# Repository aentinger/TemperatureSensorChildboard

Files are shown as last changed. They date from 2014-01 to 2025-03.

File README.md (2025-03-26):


💾 Temperatursensor Childboard
==============================



# 📸 Image

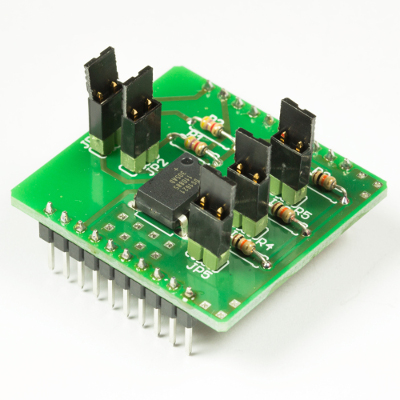
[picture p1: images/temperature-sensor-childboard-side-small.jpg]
LXRobotics P6_2 Temperatursensor Childboard


# 📂 Description

The LXRobotics Temperature Sensor Childboard offers the possiblity to measure the current temperature with high accuracy. In combination with a Radio Shield a wireless sensor network could be formed for monitoring the temperature in each room of an apartment/house. The thermostat function allows the execution of any action when a preset temperature thresholds is exceeded. For a quick and easy start, an open source Arduino library with sample programs is available.

**Features**

* Temperature range -55 °C to +125 °C
* Thermostat function
* Usage of I2C - only 2 Arduino pins required
* 8 possible I2C addresses configurable via jumpers
* Can be used with the Radioshield the Childboard Adaptershield
* Arduino Library with example programs is available on GitHub

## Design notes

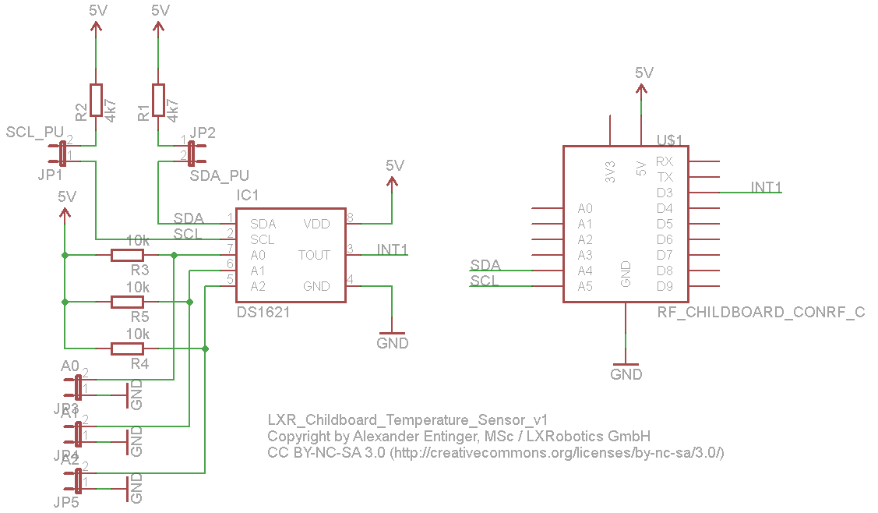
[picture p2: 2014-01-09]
hardware/lxr_childboard_temperature_sensor_v1.png

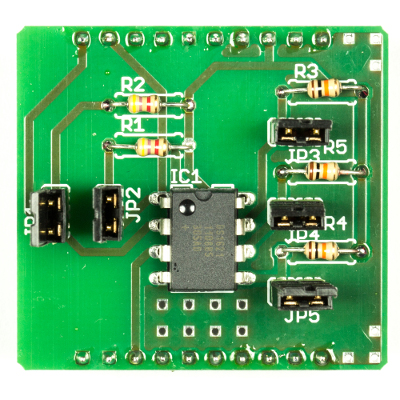
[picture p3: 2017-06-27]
images/temperature-sensor-childboard-top-small.jpg

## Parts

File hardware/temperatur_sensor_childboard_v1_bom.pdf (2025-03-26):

Menge | Schaltplan | Bezeichnung | Farnell/Conrad Bestell Nummer | Preis (1 Stück) | Gesamtpreis | Wird bestückt | Footprint | Säckchen | ESD
2 | U1 | RF Childboard Connector | 1022261 | € 0,36 | € 0,72 | | | S1
1 | IC1 | DS1621, I2C Temperatursensor | 1188024 | € 5,45 | € 5,45 | | | S2 | x
2 | R1, R2 | Widerstand, bedrahtet, 4k7, 1/8 W | 1700245 | € 0,01 | € 0,03 | | | S1
5 | JP1, JP2, JP3, JP4, JP5 | Stiftleiste, 1 x 2, 2.54 mm, Vertikal, Durchsteck | 3418285 | € 0,24 | € 1,20
5 | | Jumper, 2.54 mm, 2 Polig | 4218176 | € 0,14 | € 0,68 | | | S2 | x
3 | R3, R4, R5 | Widerstand, bedrahtet, 10 k, 1/4 W | 2329474 | € 0,03 | € 0,09
1 | Leitfähiger Schaumstoff | 1687855 | € | 2,40 | € | 2,40 | - | Bestellung von 1 Stück reicht für 50 Temperatursensor Childboards aus
| | | Summe | | € | 8,17

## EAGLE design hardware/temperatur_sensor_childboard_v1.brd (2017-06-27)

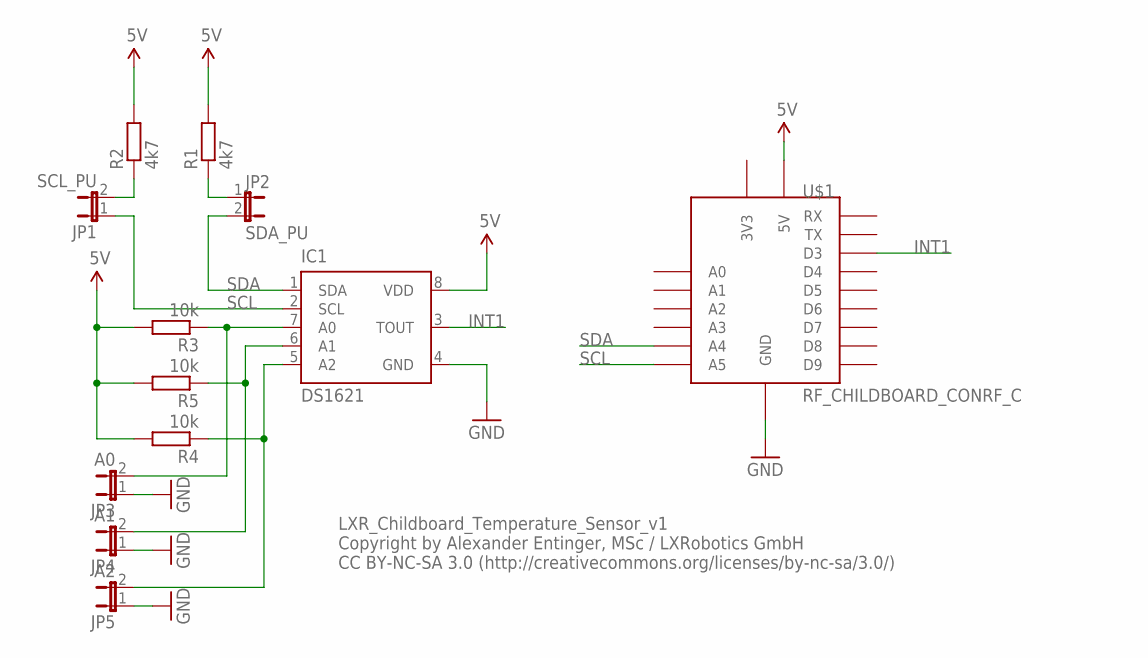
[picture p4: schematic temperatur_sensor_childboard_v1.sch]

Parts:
IC1: DS1621; DIL08
JP1: SCL_PU; JP1
JP2: SDA_PU; JP1
JP3: A0; JP1
JP4: A1; JP1
JP5: A2; JP1
R1, R2: 4k7; 0207/7
R3, R4, R5: 10k; 0207/7
U$1: RF_CHILDBOARD_CONRF_C; RF_CHILDBOARD_CON

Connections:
5V: IC1.8 (VDD), R1.2, R2.2, R3.2, R4.2, R5.2, U$1.5V
GND: IC1.4 (GND), JP3.1, JP4.1, JP5.1, U$1.GND, U$1.GND1 (GND), U$1.GND2 (GND)
INT1: IC1.3 (TOUT), U$1.D3
unnamed: JP1.2, R2.1
unnamed: IC1.7 (A0), JP3.2, R3.1
unnamed: JP2.1, R1.1
unnamed: IC1.6 (A1), JP4.2, R5.1
unnamed: IC1.5 (A2), JP5.2, R4.1
SCL: IC1.2 (SCL), JP1.1, U$1.A5
SDA: IC1.1 (SDA), JP2.2, U$1.A4

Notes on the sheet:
LXR_Childboard_Temperature_Sensor_v1 Copyright by Alexander Entinger, MSc / LXRobotics GmbH CC BY-NC-SA 3.0 (http://creativecommons.org/licenses/by-nc-sa/3.0/)

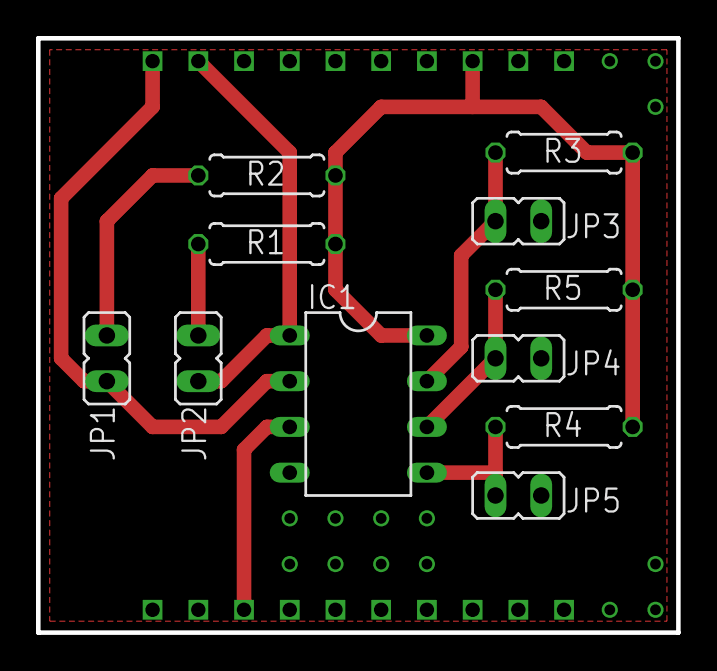
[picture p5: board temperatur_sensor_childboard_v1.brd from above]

Board: 2 copper layers, 35.6 x 33.0 mm, 12 parts (0 on the bottom side), 10 nets.

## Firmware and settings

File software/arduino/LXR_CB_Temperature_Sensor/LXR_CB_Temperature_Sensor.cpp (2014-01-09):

/**
 * @author Alexander Entinger, MSc / LXRobotics GmbH
 * @brief this library enables the user to communicate with the LXRobotics Childboard Temperature Sensor and provides functionality like reading the temperature, setting tmperature hysthere, etc. ...
 * @file LXR_CB_Temperature_Sensor.cpp
 * @license Attribution-NonCommercial-ShareAlike 3.0 Unported (CC BY-NC-SA 3.0) ( http://creativecommons.org/licenses/by-nc-sa/3.0/ )
 */

#include "LXR_CB_Temperature_Sensor.h"
#include "Wire.h"

#define READ_TEMPERATURE		(0xAA)
#define START_CONVERSION		(0xEE)
#define STOP_CONVERSION			(0x22)
#define ACCESS_TH			(0xA1)
#define ACCESS_TL			(0xA2)
#define ACCESS_CONFIG			(0xAC)

/**
 * @brief Constructor
 * @param address i2c address of the sensor
 */
LXR_CB_Temperature_Sensor::LXR_CB_Temperature_Sensor(int const address) : 
m_address(address) {

}

/**
 * @brief initializes the sensor
 */
void LXR_CB_Temperature_Sensor::begin() {
  // configure i2c sensor to measure temperature continously
  Wire.beginTransmission(m_address);
  Wire.write(ACCESS_CONFIG);
  Wire.write(0x00); // clear all flags
  Wire.endTransmission();
  delay(1);
  // start conversion
  Wire.beginTransmission(m_address);
  Wire.write(START_CONVERSION);
  Wire.endTransmission();
  delay(1);
}

/**
 * @brief returns the temperature
 */
int LXR_CB_Temperature_Sensor::get_temperature() {
  // read temperaure from sensor
  Wire.beginTransmission(m_address);
  Wire.write(READ_TEMPERATURE);
  Wire.endTransmission();
  Wire.requestFrom(m_address, 2);
  delay(1);
  if(Wire.available() == 2) {
    int8_t const temp_high_byte = Wire.read();
    Wire.read(); // we dont use the 0.5 degrees here
    return temp_high_byte;
  }
  return -128;
}

/**
 * @brief sets the temperature high and low register for thermostat control
 */
void LXR_CB_Temperature_Sensor::set_th(int const temp_high) {
  Wire.beginTransmission(m_address);
  Wire.write(ACCESS_TH);
  Wire.write(temp_high);
  Wire.write(0x00);
  Wire.endTransmission();
}
void LXR_CB_Temperature_Sensor::set_tl(int const temp_low) {
  Wire.beginTransmission(m_address);
  Wire.write(ACCESS_TL);
  Wire.write(temp_low);
  Wire.write(0x00);
  Wire.endTransmission();  
}
 
/**
 * @brief reads the temperature high and low for thermostat control
 */
int LXR_CB_Temperature_Sensor::get_th() {
  Wire.beginTransmission(m_address);
  Wire.write(ACCESS_TH);
  Wire.endTransmission();
  Wire.requestFrom(m_address, 2);
  delay(1);
  if(Wire.available() == 2) {
    int8_t const th_high = Wire.read();
    Wire.read(); // we dont use the 0.5 degree here
    return th_high;
  }
  return -128;
}
int LXR_CB_Temperature_Sensor::get_tl() {
  Wire.beginTransmission(m_address);
  Wire.write(ACCESS_TL);
  Wire.endTransmission();
  Wire.requestFrom(m_address, 2);
  delay(1);
  if(Wire.available() == 2) {
    int8_t const tl_high = Wire.read();
    Wire.read(); // we dont use the 0.5 degree here
    return tl_high;
  }
  return -128; 
}

/**
 * @brief attaches a callback function which is called in case of an thermostat event
 */
void LXR_CB_Temperature_Sensor::attach_thermostat_event_callback(thermostat_event_callback_function cb) {
  if(cb != 0) attachInterrupt(1, cb, CHANGE);  
}

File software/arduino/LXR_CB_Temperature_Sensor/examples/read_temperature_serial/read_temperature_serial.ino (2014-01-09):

/**
 * @author Alexander Entinger, MSc / LXRobotics GmbH
 * @brief this sketch demonstrates how to read the temperature of the LXRobotics Childboard Temperature Sensor using the LXR_Childboard_Temperature_Sensor Library
 * @file read_temperature_serial.ino
 * @license Attribution-NonCommercial-ShareAlike 3.0 Unported (CC BY-NC-SA 3.0) ( http://creativecommons.org/licenses/by-nc-sa/3.0/ )
 */

#include "LXR_CB_Temperature_Sensor.h"
#include <Wire.h> // dont forget this

// instantiate sensor
LXR_CB_Temperature_Sensor temp_sensor(SENSOR_DEFAULT_ADDRESS);

void setup() {
  // dont forget to call this first
  Wire.begin();
  // initialize sensor
  temp_sensor.begin();
  // initialize serial interface  
  Serial.begin(115200);
}

void loop() {
  int const temperature = temp_sensor.get_temperature();
  if(temperature != -128) {
    Serial.print("Temperature = ");
    Serial.print(temperature);
    Serial.println(" C");
  } else {
   Serial.println("Error, could not read temperature"); 
  }
  delay(1000); 
}

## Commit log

2014-01-15 initial checkin of temperatursensor
2017-06-27 Adding hardware + images
    [temperatur_sensor_childboard_v1.brd, temperatur_sensor_childboard_v1.sch]
2025-03-26 Add BOM.

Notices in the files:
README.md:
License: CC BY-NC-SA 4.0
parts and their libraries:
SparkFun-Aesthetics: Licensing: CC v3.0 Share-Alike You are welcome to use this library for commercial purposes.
